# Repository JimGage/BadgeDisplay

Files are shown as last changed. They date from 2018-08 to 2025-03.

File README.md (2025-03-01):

# Badge Display

## Introduction
This was a bit of an art project that I did for SIGGRAPH 2018. Path tracing seemed to be a big theme that year and I wanted a badge that spent the day path tracing. The plan was that it would start off fuzzy in the morning and by the end of the day render a clear image.

## Images

The final badge

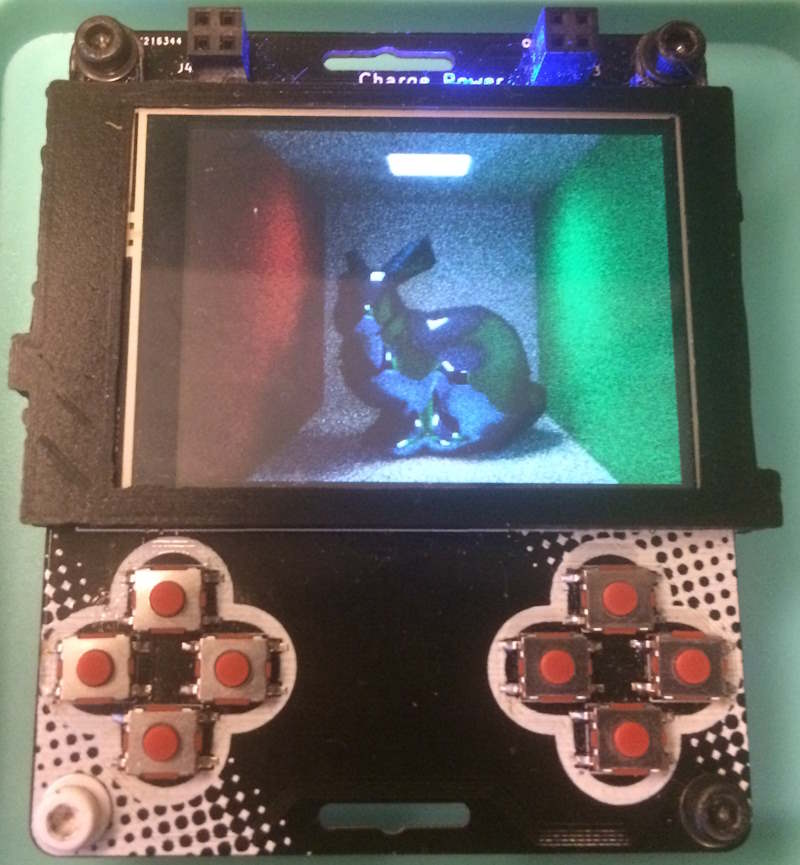
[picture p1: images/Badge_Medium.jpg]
Finished badge


The images that were rendered during the first four days of the conference. Each image took around 10 hours on 72MHz ARM processor.

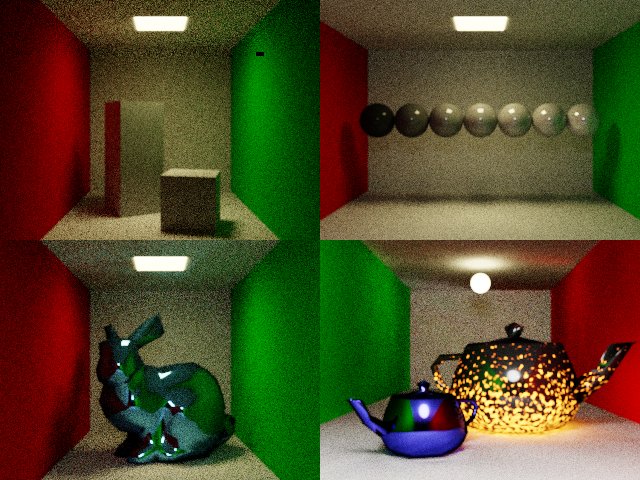
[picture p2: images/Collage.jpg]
Four images rendered


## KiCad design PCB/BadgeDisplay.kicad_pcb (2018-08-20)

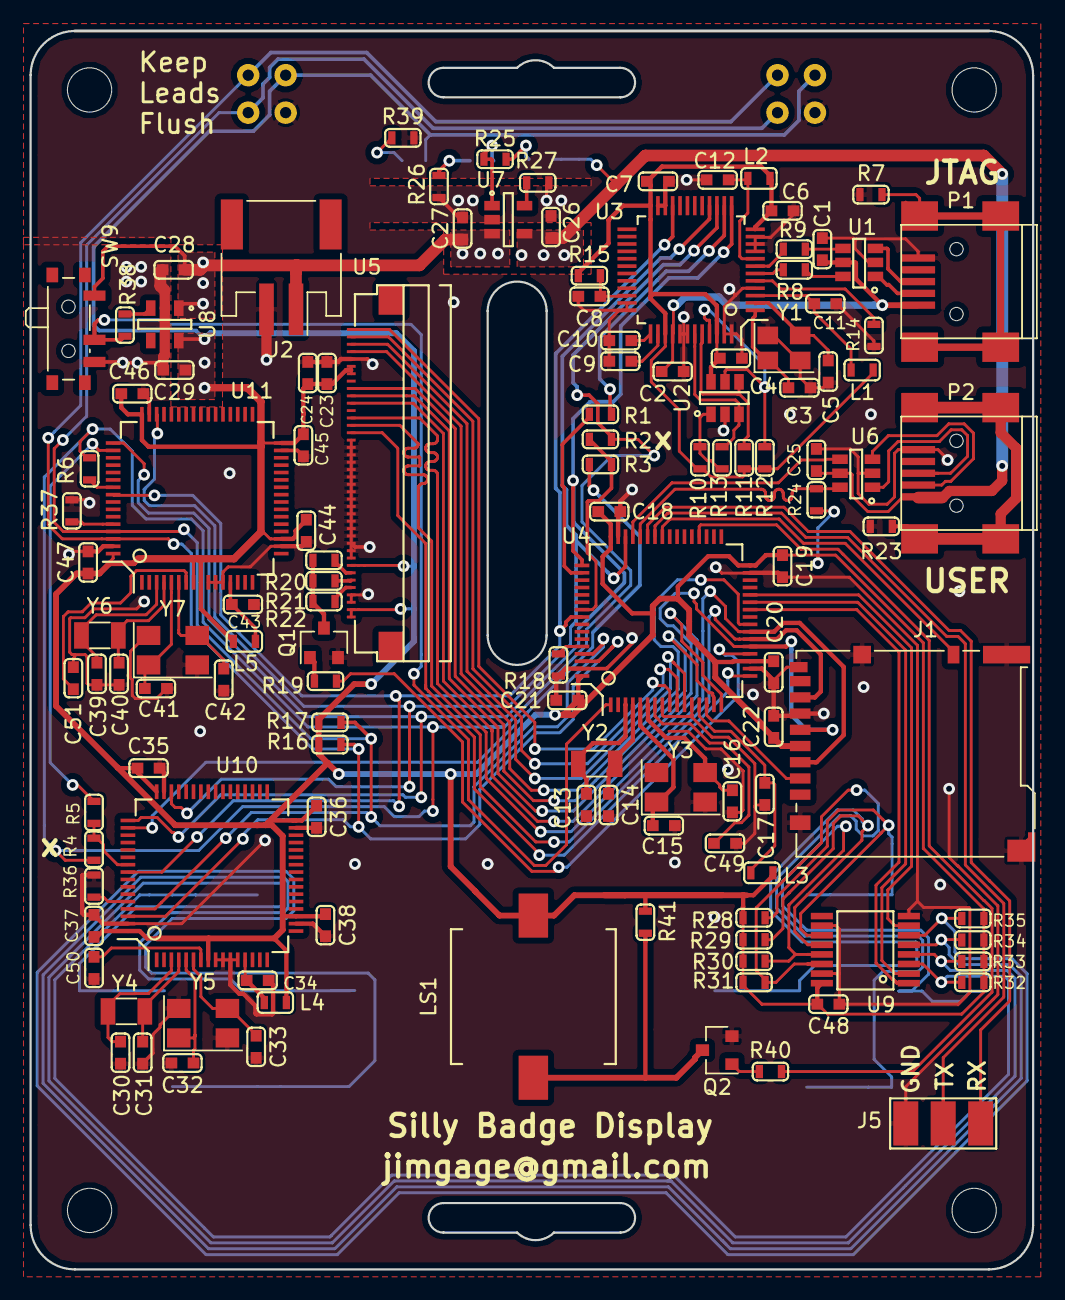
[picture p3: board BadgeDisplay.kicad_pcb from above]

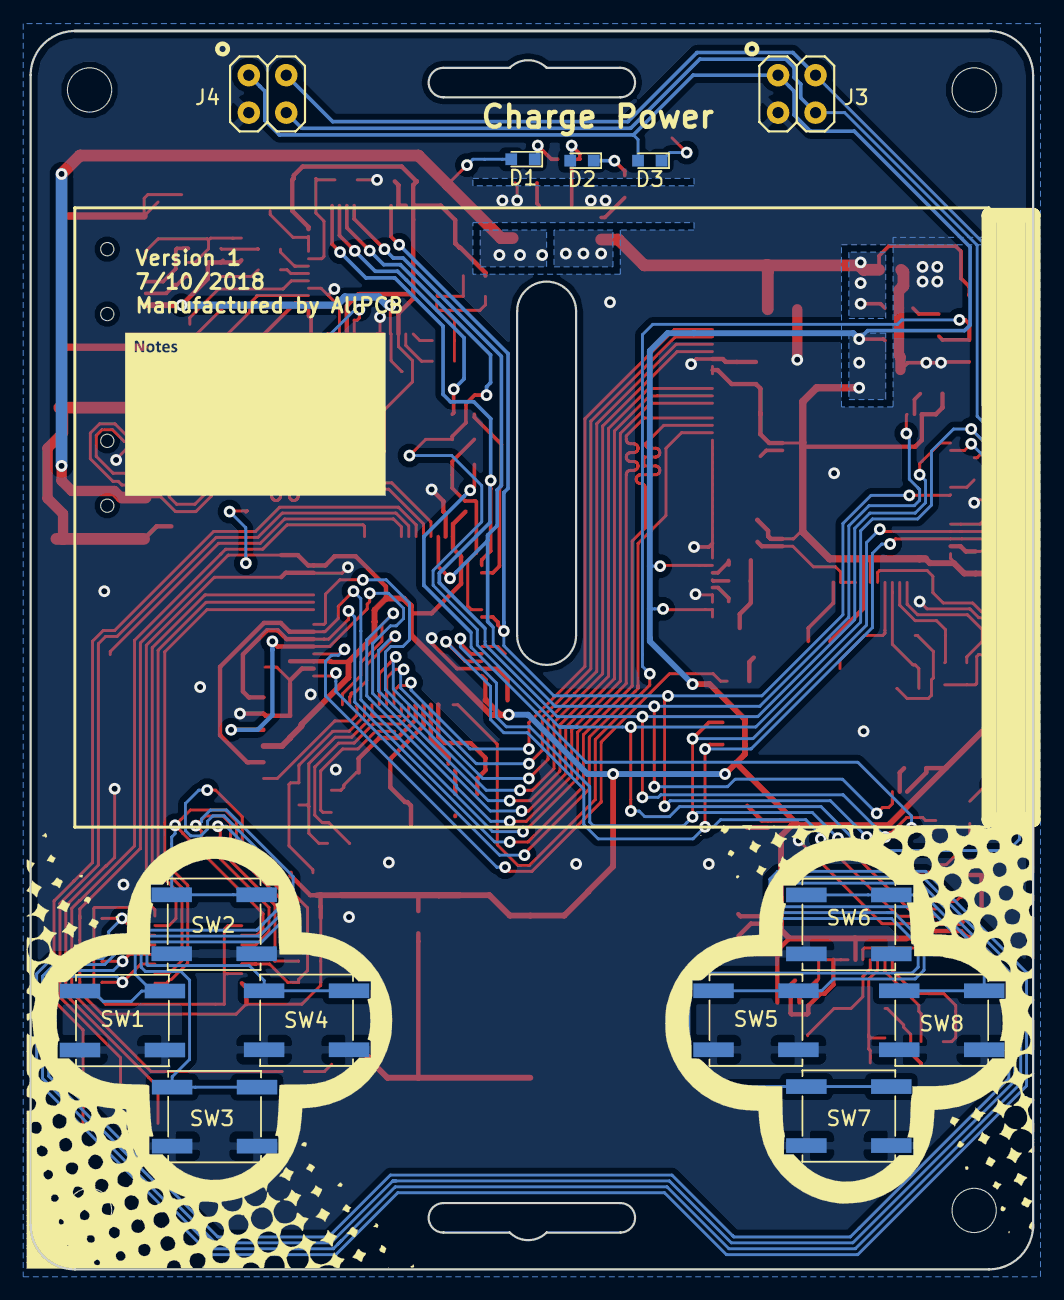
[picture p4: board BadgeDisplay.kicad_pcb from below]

Board: 2 copper layers, 68.0 x 84.0 mm, 137 parts (13 on the bottom side), 105 nets.

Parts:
C1, C4, C6, C7, C9, C10, C17, C18, C19, C20, C21, C22, C23, C25, C34, C35, C36, C37, C38, C43, C44, C45, C46, C47, C48, C49, C50, C51: 0u1; C_0603
C2, C11, C12, C26, C27, C28, C29: 4u7; C_0603
C3, C5: 16p; C_0603
C8: 10n; C_0603
C13, C14, C30, C31, C39, C40: 22p; C_0603
C15, C16, C32, C33, C41, C42: 36p; C_0603
C24: 1u; C_0603
D1, D2, D3: LED; LED_0603
J1: Micro_SD_Card_Det; Hirose_DM3BT-DSF-PEJS
J2: Conn_01x02; JST_PH_S2B-PH-SM4-TB_02x2.00mm_Angled
J3, J4: AddOn; AddOnConnector
J5: Conn_01x03; 3pin_smd
L1, L2, L3, L4, L5: Bead; L_0603
LS1: Speaker_Crystal; AST1109MLTRQ
P1, P2: USB_MINI; USB_Mini-B
Q1, Q2: MMBT3904; SOT-23
R1, R3, R5, R6: 0; R_0603
R2, R4: X; R_0603
R7, R23: 1; R_0603
R8, R9: 22; R_0603
R10, R11, R12, R15, R18, R28, R29, R30, R31, R32, R33, R34, R35, R36, R37: 10K; R_0603
R13: 2K; R_0603
R14: 12K; R_0603
R16, R17: 4k7; R_0603
R19, R40, R41: 1K; R_0603
R20, R21, R22, R38: 10; R_0603
R24: 1K5; R_0603
R25, R26: 470; R_0603
R27: 2k; R_0603
R39: 100; R_0603
SW1: LEFT_LEFT; SW_SPST_EVPBF
SW2: LEFT_UP; SW_SPST_EVPBF
SW3: LEFT_DOWN; SW_SPST_EVPBF
SW4: LEFT_RIGHT; SW_SPST_EVPBF
SW5: RIGHT_LEFT; SW_SPST_EVPBF
SW6: RIGHT_UP; SW_SPST_EVPBF
SW7: RIGHT_DOWN; SW_SPST_EVPBF
SW8: RIGHT_RIGHT; SW_SPST_EVPBF
SW9: SW_SPDT; SW_SPDT_PCM12
U1, U6: USBLC6-2; SOT-23-6
U2: 93LC56BT-OT; SOT-23-6
U3: FT232H; LQFP-48_7x7mm_Pitch0.5mm
U4, U10, U11: STM32F303RE-LQFP64; LQFP-64_10x10mm_Pitch0.5mm
U5: LCD_40PIN; 40Pin_conn_05Pitch
U7: MCP73831T; SOT-23-5
U8: TLV75733PDBVR; SOT-23-5
U9: 74HC165; TSSOP-16_4.4x5mm_Pitch0.65mm
Y1: 12MHz; Crystal_SMD_3225-4pin_3.2x2.5mm
Y2, Y4, Y6: 32.768KHz; Crystal_SMD_3215-2pin_3.2x1.5mm
Y3, Y5, Y7: 8MHz; Crystal_SMD_5032-4pin_5.0x3.2mm

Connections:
+3.3VA: C4.1, C6.1, C7.1, L1.2, L2.1, R10.1, R11.1, R12.1, R15.1, U2.6, U3.12, U3.24, U3.39, U3.46
+3V3: C18.1, C19.1, C20.1, C21.1, C22.1, C23.1, C24.1, C29.1, C35.1, C36.1, C37.1, C38.1, C44.1, C45.1, C46.1, C47.1, C48.1, D3.2, J1.4, J3.1, J4.1, L3.2, L4.2, L5.2, LS1.1, R16.1, R17.1, R24.1, R28.1, R29.1, R30.1, R31.1, R32.1, R33.1, R34.1, R35.1, R41.1, U4.19, U4.32, U4.48, U4.64, U5.6, U5.7, U5.33, U5.39, U5.40, U8.5, U9.16, U10.8, U10.19, U10.32, U10.48, U10.64, U11.8, U11.9, U11.19, U11.32, U11.48, U11.64
+5V: C25.1, C26.1, D1.2, P2.1, U6.5, U7.4
/FT232H/JTAG-TDI: R1.2, U3.14
/FT232H/JTAG-TDO: R2.2, R4.2, R6.1, U3.15
/JNTRST: U3.21, U4.56, U10.56, U11.56
/JTCK: U3.13, U4.49, U10.49, U11.49
/JTMS: U3.16, U4.46, U10.46, U11.46
/LCD_SD/BK_LIGHT: R19.2, U4.20
/LCD_SD/CARD_DETECT: J1.10, U4.41
/LCD_SD/CMD: U4.16, U5.11
/LCD_SD/LCD_CS: U4.15, U5.9
/LCD_SD/LCD_RESET: U4.17, U5.15
/LCD_SD/SCLK: J1.5, U4.21, U5.10
/LCD_SD/SD_CS: J1.2, U4.14
/Power/BATTERY: R38.2, SW9.2, U4.1
/Power/USB+: R24.2, U4.44, U6.6
/Power/USB-: U4.45, U6.4
/Power/VBAT: C27.1, C28.1, J2.1, SW9.1, U7.3, U8.1
/SCL: J3.3, J4.3, R17.2, U4.61, U10.61, U11.61
/SDA: J3.4, J4.4, R16.2, U4.62, U10.62, U11.62
/STM_Master/ANALOG0: U4.9, U5.1
/STM_Master/ANALOG1: U4.10, U5.2
/STM_Master/ANALOG2: U4.11, U5.3
/STM_Master/ANALOG3: U4.24, U5.4
/STM_Master/BUTTON_CLOCK: U4.27, U9.2
/STM_Master/BUTTON_DATA: U4.28, U9.7
/STM_Master/BUTTON_LATCH: U4.26, U9.1
/STM_Master/JTDI: R1.1, U4.50
/STM_Master/JTDO: R2.1, R3.2, U4.55
/STM_Master/MISO: J1.7, U4.22, U5.14
/STM_Master/MOSI: J1.3, U4.23, U5.13
/STM_Master/NRST: C49.1, U4.7
/STM_Master/USART1_RX: J5.1, U4.43
/STM_Master/USART1_TX: J5.2, U4.42
/STM_SLAVE0/JTDI: R3.1, U10.50
/STM_SLAVE0/JTDO: R4.1, R5.2, U10.55
/STM_SLAVE0/NRST: C50.1, U10.7
/STM_SLAVE1/JTDI: R5.1, U11.50
/STM_SLAVE1/JTDO: R6.2, U11.55
/STM_SLAVE1/NRST: C51.1, U11.7
GND: C1.2, C2.2, C3.2, C4.2, C5.2, C6.2, C7.2, C8.2, C9.2, C10.2, C11.2, C12.2, C13.2, C14.2, C15.2, C16.2, C17.2, C18.2, C19.2, C20.2, C21.2, C22.2, C23.2, C24.2, C25.2, C26.2, C27.2, C28.2, C29.2, C30.2, C31.2, C32.2, C33.2, C34.2, C35.2, C36.2, C37.2, C38.2, C39.2, C40.2, C41.2, C42.2, C43.2, C44.2, C45.2, C46.2, C47.2, C48.2, C49.2, C50.2, C51.2, J1.6, J1.9, J1.11, J2.2, J3.2, J4.2, J5.3, P1.5, P2.5, Q1.2, Q2.2, R7.1, R14.1, R18.1, R23.1, R26.2, R27.2, R36.1, R37.1, R39.2, SW1.1, SW2.1, SW3.1, SW4.1, SW5.1, SW6.1, SW7.1, SW8.1, SW9.3, U1.2, U2.2, U3.4, U3.9, U3.10, U3.11, U3.22, U3.23, U3.35, U3.36, U3.41, U3.42, U3.47, U3.48, U4.8, U4.12, U4.18, U4.31, U4.47, U4.63, U5.5, U5.16, U5.17, U5.18, U5.19, U5.20, U5.21, U5.22, U5.23, U5.24, U5.25, U5.26, U5.27, U5.28, U5.29, U5.30, U5.31, U5.32, U5.37, U5.38, U6.2, U7.2, U8.2, U9.8, U9.10, U9.15, U10.9, U10.10, U10.11, U10.12, U10.18, U10.31, U10.47, U10.63, U11.10, U11.11, U11.12, U11.18, U11.31, U11.47, U11.63, Y1.2, Y1.4, Y3.2, Y3.4, Y5.2, Y5.4, Y7.2, Y7.4
unnamed: C1.1, C2.1, P1.1, U1.5, U3.40
unnamed: C3.1, U3.1, Y1.1
unnamed: C5.1, U3.2, Y1.3
unnamed: C8.1, R15.2, U3.34
unnamed: C9.1, U3.38
unnamed: C10.1, U3.37
unnamed: C11.1, L1.1, U3.3
unnamed: C12.1, L2.2, U3.8
unnamed: C13.1, U4.3, Y2.1
unnamed: C14.1, U4.4, Y2.2
unnamed: C15.1, U4.5, Y3.1
unnamed: C16.1, U4.6, Y3.3
unnamed: C17.1, L3.1, U4.13
unnamed: C30.1, U10.3, Y4.1
unnamed: C31.1, U10.4, Y4.2
unnamed: C32.1, U10.5, Y5.1
unnamed: C33.1, U10.6, Y5.3
unnamed: C34.1, L4.1, U10.13
unnamed: C39.1, U11.3, Y6.1
unnamed: C40.1, U11.4, Y6.2
unnamed: C41.1, U11.5, Y7.1
unnamed: C42.1, U11.6, Y7.3
unnamed: C43.1, L5.1, U11.13
unnamed: D1.1, R25.1
unnamed: D2.1, R26.1
unnamed: D2.2, R25.2, U7.1
unnamed: D3.1, R39.1
unnamed: LS1.2, Q2.3, R41.2
unnamed: P1.2, U1.1
unnamed: P1.3, U1.3
unnamed: P1.6, R7.2
unnamed: P2.2, U6.3
unnamed: P2.3, U6.1
unnamed: P2.6, R23.2
unnamed: Q1.1, R19.1
unnamed: Q1.3, R20.2, R21.2, R22.2
unnamed: Q2.1, R40.1
unnamed: R8.1, U3.6
unnamed: R8.2, U1.6
unnamed: R9.1, U3.7
unnamed: R9.2, U1.4
unnamed: R10.2, R13.2, U2.1
unnamed: R11.2, U2.4, U3.44
unnamed: R12.2, U2.5, U3.45
unnamed: R13.1, U2.3, U3.43
unnamed: R14.2, U3.5
unnamed: R18.2, U4.60
unnamed: R20.1, U5.34
unnamed: R21.1, U5.35
unnamed: R22.1, U5.36
unnamed: R27.1, U7.5
unnamed: R28.2, SW2.2, U9.11
unnamed: R29.2, SW4.2, U9.12
unnamed: R30.2, SW1.2, U9.13
unnamed: R31.2, SW3.2, U9.14
unnamed: R32.2, SW6.2, U9.3
unnamed: R33.2, SW8.2, U9.4
unnamed: R34.2, SW5.2, U9.5
unnamed: R35.2, SW7.2, U9.6
unnamed: R36.2, U10.60
unnamed: R37.2, U11.60
unnamed: R38.1, U8.3
unnamed: R40.2, U4.36

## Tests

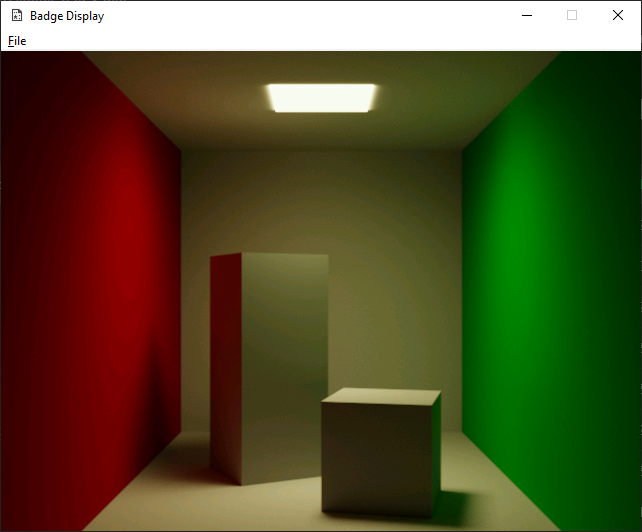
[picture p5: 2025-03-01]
images/Test4_1Week.png
